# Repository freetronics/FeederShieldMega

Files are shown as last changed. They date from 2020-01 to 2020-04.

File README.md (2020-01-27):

Feeder Shield Mega
==================
Copyright 2018-2020 Freetronics Pty Ltd  www.freetronics.com  

Pick and place feeder controller for DIY feeders. Compatible with the
0816 feeders designed by MGRL:

  https://docs.mgrl.de/maschine:pickandplace:feeder:0816feeder

These feeders are commonly used with DIY pick and place machines
running OpenPNP:

  http://openpnp.org

Run the MGRL feeder control firmware.

Adds an I2C display that can be used for reporting events and part
counts.

Uses 10-way IDC cables to connect batches of 4 feeders. Mates to the
MGRL0816 Feeder Link board, which bridges across the 4-pin connections
on 4 feeders mounted side by side.

Features:

 * 24 feeder outputs
 * PWM output and feedback input
 * GND and 5V supply to feeders
 * Software controlled feeder power
 * 128x32 OLED

You can view more online at:

  http://www.freetronics.com.au/fsm

INSTALLATION
------------
The design is saved as an EAGLE project. EAGLE PCB design software is
available from www.cadsoftusa.com free for non-commercial use. To use
this project download it and place the directory containing these files
into the "eagle" directory on your computer. Then open EAGLE and
navigate to the project.

DISTRIBUTION
------------
The specific terms of distribution of this project are governed by the
license referenced below.

LICENSE
-------
Licensed under the TAPR Open Hardware License (www.tapr.org/OHL).
The "license" folder within this repository also contains a copy of
this license in plain text format.

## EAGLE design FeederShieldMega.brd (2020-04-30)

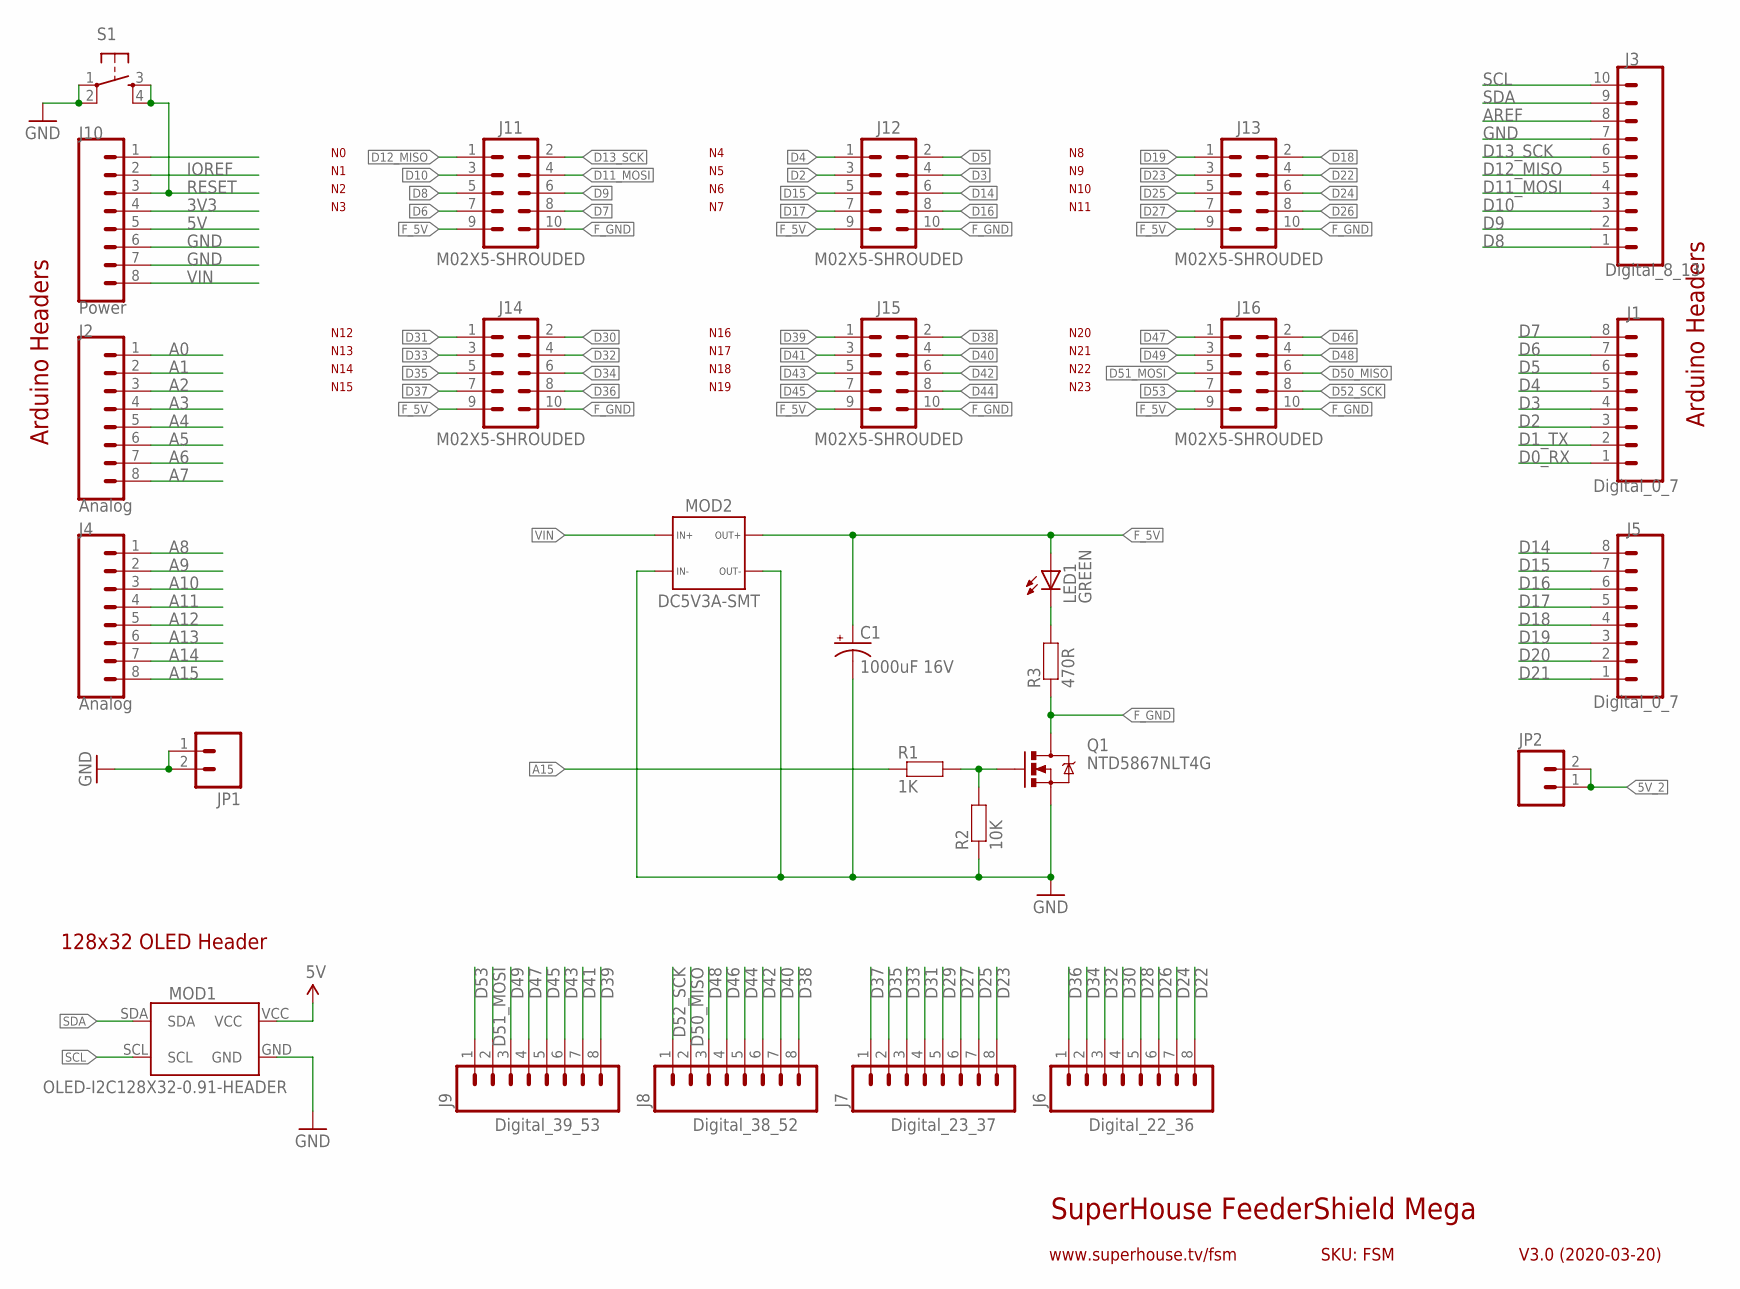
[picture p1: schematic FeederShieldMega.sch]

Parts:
C1: 1000uF 16V; CPOL-RADIAL-5.08-10X18-FLAT
J1, J5: Digital_0_7; 1X08-P-BELOW
J2, J4: Analog; 1X08-P-BELOW
J3: Digital_8_13; 1X10-P-BELOW
J6: Digital_22_36; 1X08-P-BELOW
J7: Digital_23_37; 1X08-P-BELOW
J8: Digital_38_52; 1X08-P-BELOW
J9: Digital_39_53; 1X08-P-BELOW
J10: Power; 1X08-P-BELOW
J11, J12, J13, J14, J15, J16: M02X5-SHROUDED; 2X05-2.54-SHROUDED
JP1, JP2: M02-PIN-BELOW; 1X02-P-BELOW
LED1: GREEN; LED-0603
MOD1: OLED-I2C128X32-0.91-HEADER; OLED-128X32-0.91-HEADER
MOD2: DC5V3A-SMT
Q1: NTD5867NLT4G; DPACK
R1: 1K; R0603
R2: 10K; R0603
R3: 470R; R0603
S1: TAC_SWITCH-PTH-6; TACTILE-PTH-6MM

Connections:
3V3: J10.4
5V: J10.5, MOD1.VCC
5V_2: JP2.1, JP2.2
A0: J2.1
A1: J2.2
A2: J2.3
A3: J2.4
A4: J2.5
A5: J2.6
A6: J2.7
A7: J2.8
A8: J4.1
A9: J4.2
A10: J4.3
A11: J4.4
A12: J4.5
A13: J4.6
A14: J4.7
A15: J4.8, R1.1
AREF: J3.8
D0_RX: J1.1
D1_TX: J1.2
D2: J1.3, J12.3
D3: J1.4, J12.4
D4: J1.5, J12.1
D5: J1.6, J12.2
D6: J1.7, J11.7
D7: J1.8, J11.8
D8: J3.1, J11.5
D9: J3.2, J11.6
D10: J3.3, J11.3
D11_MOSI: J3.4, J11.4
D12_MISO: J3.5, J11.1
D13_SCK: J3.6, J11.2
D14: J5.8, J12.6
D15: J5.7, J12.5
D16: J5.6, J12.8
D17: J5.5, J12.7
D18: J5.4, J13.2
D19: J5.3, J13.1
D20: J5.2
D21: J5.1
D22: J6.8, J13.4
D23: J7.8, J13.3
D24: J6.7, J13.6
D25: J7.7, J13.5
D26: J6.6, J13.8
D27: J7.6, J13.7
D28: J6.5
D29: J7.5
D30: J6.4, J14.2
D31: J7.4, J14.1
D32: J6.3, J14.4
D33: J7.3, J14.3
D34: J6.2, J14.6
D35: J7.2, J14.5
D36: J6.1, J14.8
D37: J7.1, J14.7
D38: J8.8, J15.2
D39: J9.8, J15.1
D40: J8.7, J15.4
D41: J9.7, J15.3
D42: J8.6, J15.6
D43: J9.6, J15.5
D44: J8.5, J15.8
D45: J9.5, J15.7
D46: J8.4, J16.2
D47: J9.4, J16.1
D48: J8.3, J16.4
D49: J9.3, J16.3
D50_MISO: J8.2, J16.6
D51_MOSI: J9.2, J16.5
D52_SCK: J8.1, J16.8
D53: J9.1, J16.7
F_5V: C1.1 (+), J11.9, J12.9, J13.9, J14.9, J15.9, J16.9, LED1.A, MOD2.3A (3), MOD2.3B (3)
F_GND: J11.10, J12.10, J13.10, J14.10, J15.10, J16.10, Q1.2 (D), R3.1
GND: C1.2 (-), J3.7, J10.6, J10.7, JP1.1, JP1.2, MOD1.GND, MOD2.1A (1), MOD2.1B (1), MOD2.4A (4), MOD2.4B (4), Q1.3 (S), R2.1, S1.1, S1.2
IOREF: J10.2
unnamed: Q1.1 (G), R1.2, R2.2
unnamed: LED1.C, R3.2
RESET: J10.3, S1.3, S1.4
SCL: J3.10, MOD1.SCL
SDA: J3.9, MOD1.SDA
VIN: J10.8, MOD2.2A (2), MOD2.2B (2)

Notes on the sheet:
SuperHouse FeederShield Mega
V3.0 (2020-03-20)
www.superhouse.tv/fsm
SKU: FSM
Arduino Headers
128x32 OLED Header
N10
N11
N12
N13
N14
N15
N16
N17
N18
N19
N20
N21
N22
N23

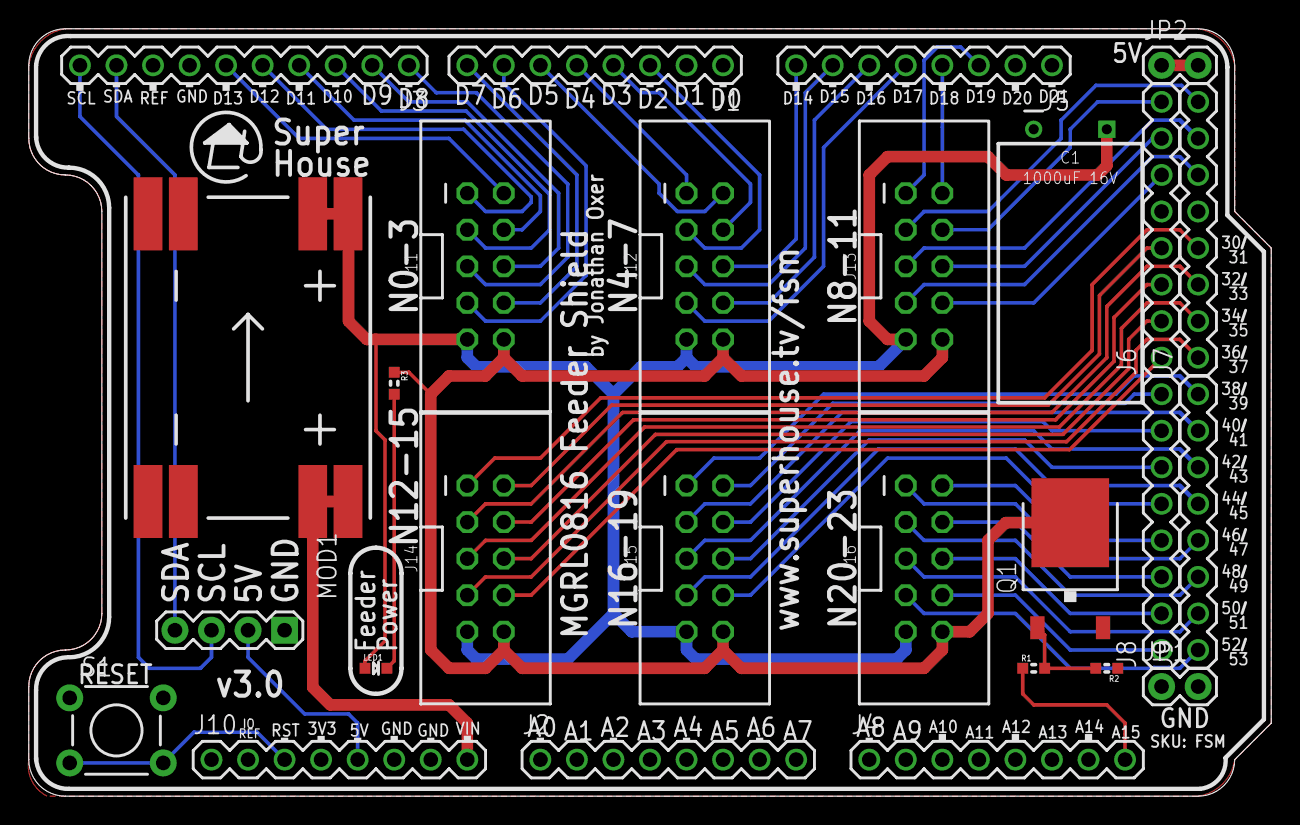
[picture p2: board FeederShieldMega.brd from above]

Board: 2 copper layers, 86.4 x 53.3 mm, 27 parts (0 on the bottom side), 60 nets.

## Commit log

2018-07-12 Initial layout
    [FeederShieldMega.brd, FeederShieldMega.sch]
2018-07-12 Tweaks for v1.0 release
    [FeederShieldMega.brd, FeederShieldMega.sch]
2018-07-12 DRC for release v1.0
    [FeederShieldMega.brd]
2020-01-27 Major rework to use 10-way IDC connections for v2.0 release
    [FeederShieldMega.brd, FeederShieldMega.sch]
2020-04-30 Added 5V 3A voltage regulator and removed 2 bulk decoupling caps for v3.0 release
    [FeederShieldMega.brd, FeederShieldMega.sch]

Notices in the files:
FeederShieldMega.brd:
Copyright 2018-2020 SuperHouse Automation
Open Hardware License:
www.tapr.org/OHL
